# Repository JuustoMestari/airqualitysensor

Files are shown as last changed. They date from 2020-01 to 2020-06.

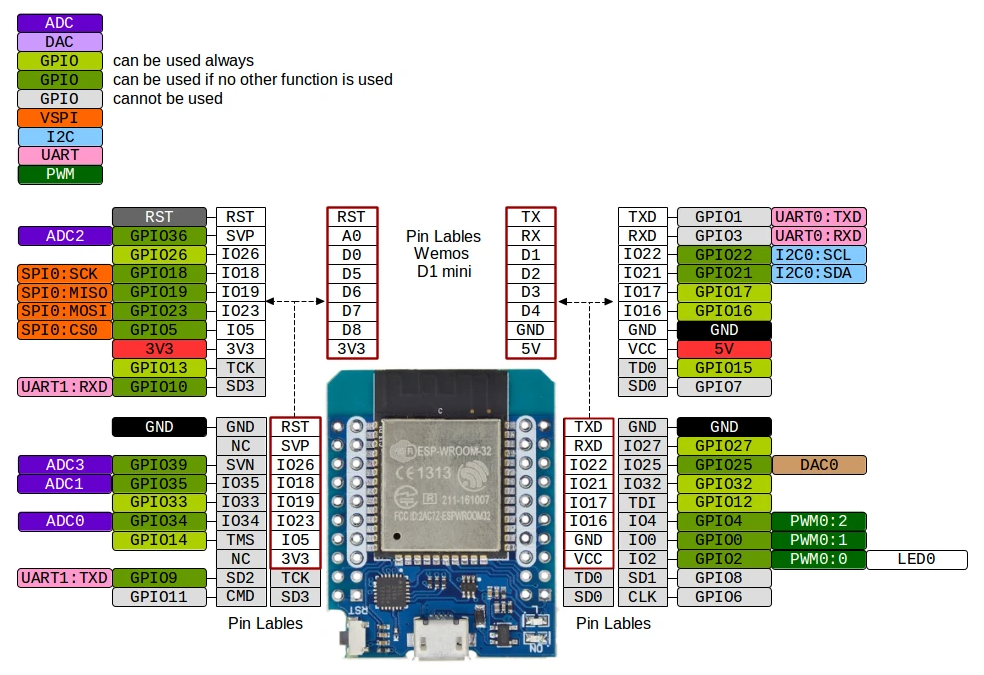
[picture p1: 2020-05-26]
docs/esp32_mini_pinout.png

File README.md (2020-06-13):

# Air quality sensor
## Device
- ESP32 board : https://ebay.to/39Jhv0x
## Air quality sensor
- PMS7003 : https://download.kamami.com/p564008-p564008-PMS7003%20series%20data%20manua_English_V2.5.pdf
## Temperature/Humidity sensor
- DHT22 : https://www.sparkfun.com/datasheets/Sensors/Temperature/DHT22.pdf
## Pinout
| ESP32 | DHT22 | PMS7003 |
| --- |:---:| ---:|
|VIN		 | | |
|GND		 | | |
|RST | |RST |
|IO17		 | |RX |
|IO16		 | |TX |
|3V3	 |VCC |VCC |
|GND	 |GND |GND |	
|IO4 |DATA | |	

## Libraries
- Micro Web Server : https://github.com/jczic/MicroWebSrv
- pms7003+AQI : https://github.com/pkucmus/micropython-pms7003

## firmware
- Download latest version of micropython for ESP32 : http://micropython.org/download#esp32
- Flash using instructions from micropython firmware download website using esptool : https://github.com/espressif/esptool . Esptool requires python module "pyserial" (pip install pyserial)
```console
python esptool.py --chip esp32 --port COM3 erase_flash
```
```console
python esptool.py --chip esp32 --port COM3 --baud 460800 write_flash -z 0x1000 esp32-20190125-v1.xxxxx.bin
```

## rshell
Install with 
```console
sudo pip3 install rshell
```
```console
pip install rshell
```
List files on device
```console
rshell -p COM3 ls /pyboard
```
Clear files on device
```console
rshell -p COM3 rm -r /pyboard/
```
Copy all files to device (doesn't seem to work on windows)
```console
rshell -p COM3 cp -r device/* /pyboard
```
Copy single file at a time (windows)
```console
rshell -p COM3 cp main.py /pyboard
```

## serial
You can monitor what is going on with the device by connecting with a client like Putty.  
Set port (COMX or /dev/ttyUSBX) and speed to 115200. Press reset button (EN) on ESP32.

# TODO
- ~~sync time with ntp server~~
- ~~add DHT22 logic~~
- improve logic if pms7003 returns AQI of 0
- improve UI
  - ~~add gauges~~
  - ~~add time series (1 min, 10min, 30min, 1 hour)~~
  - ~~add current time~~
  - ~~add flash space~~
  - ~~use progressbar for flash space~~
  - automatically refresh UI every minute
  - ~~improve page's css so graph is responsive, using flex~~
  - Fix metric colors
  - ~~change graph scale depending on period (1,10,30,60)~~
  - ~~improve display on mobile~~

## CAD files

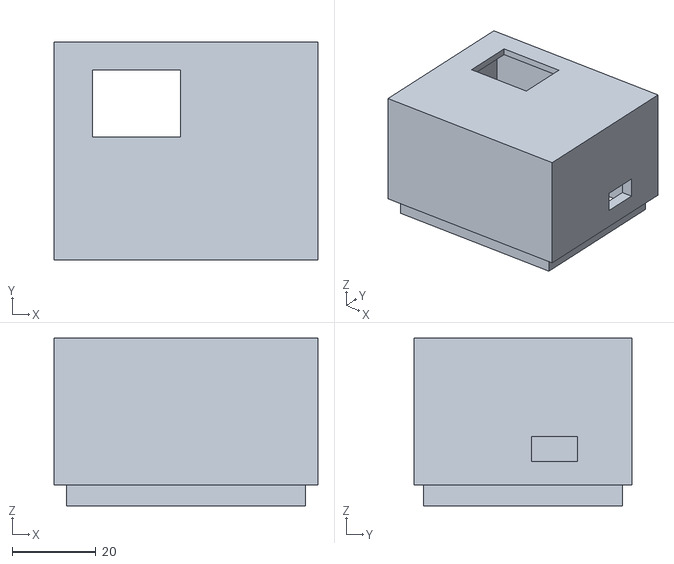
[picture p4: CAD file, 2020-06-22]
case/case_cover.stl
63.0 x 52.0 x 40.0

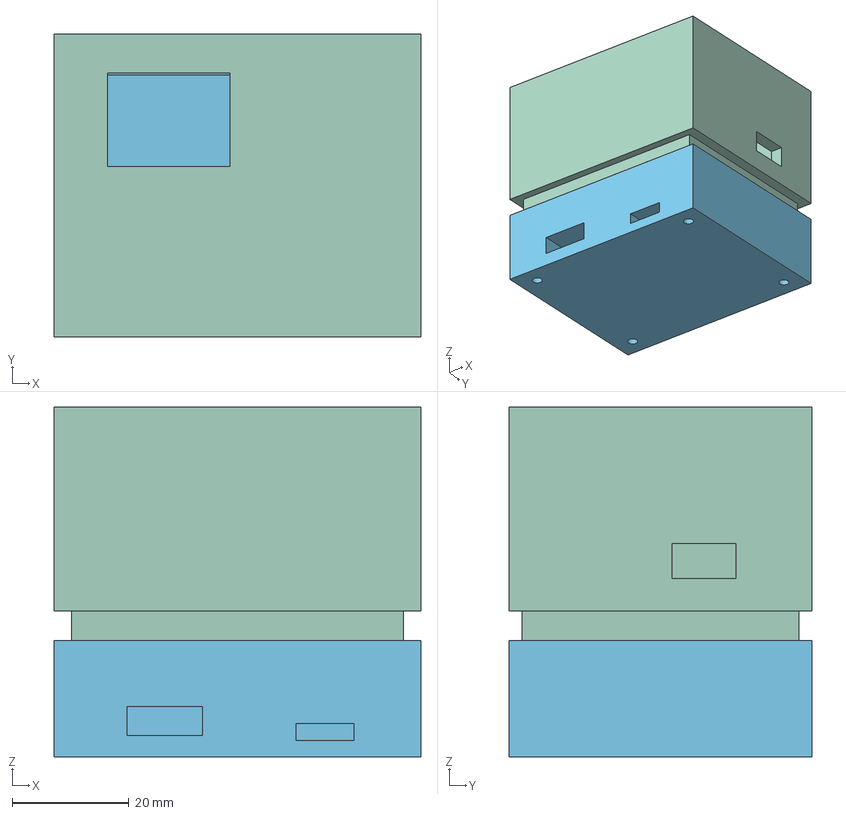
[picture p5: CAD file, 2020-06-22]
case/case.FCStd
63.0 x 52.0 x 60.0 mm
cover

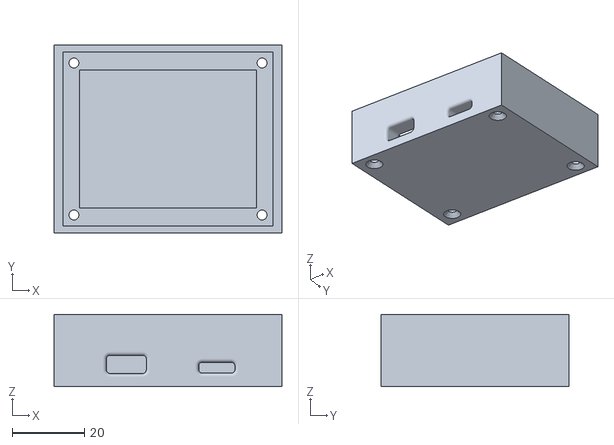
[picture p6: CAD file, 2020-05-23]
case/case_1.stl
63.0 x 52.0 x 20.0

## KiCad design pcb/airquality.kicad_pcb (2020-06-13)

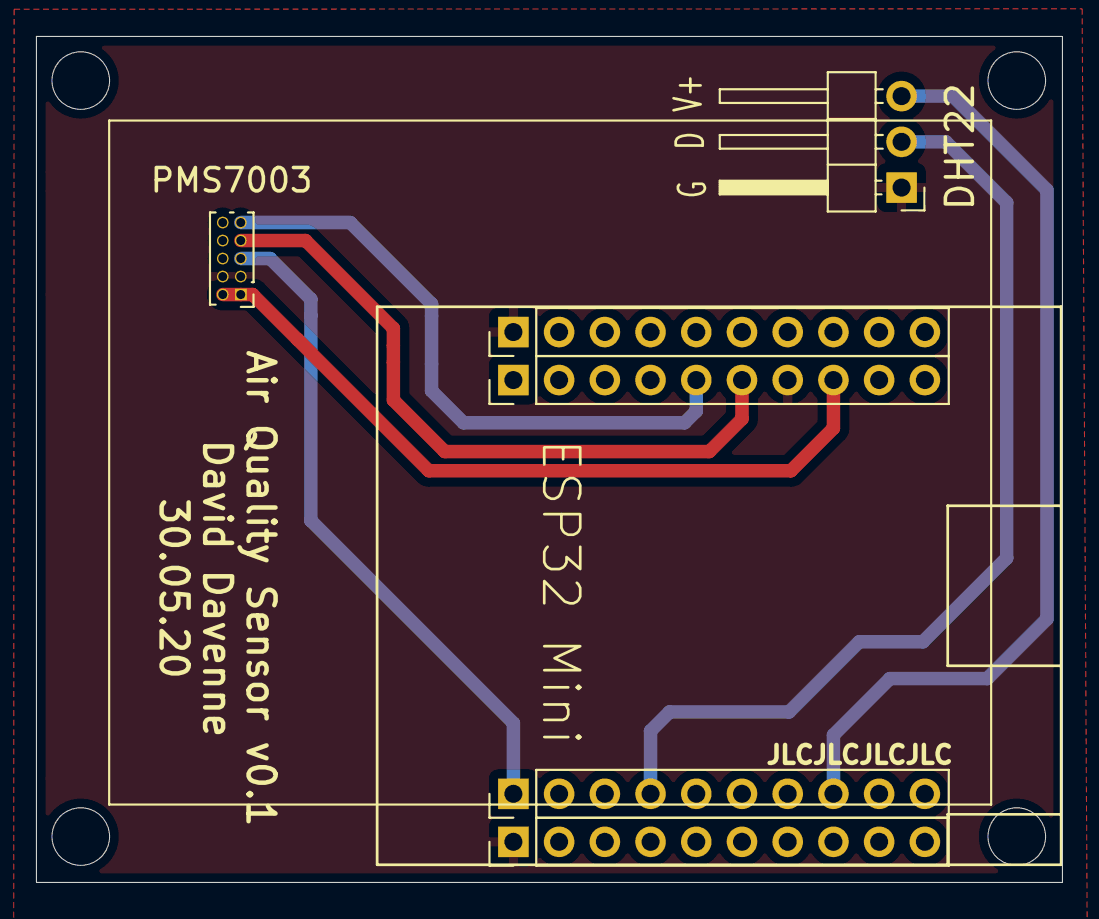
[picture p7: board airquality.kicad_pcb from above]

Board: 2 copper layers, 57.0 x 47.0 mm, 3 parts (0 on the bottom side), 7 nets.

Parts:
DHT22: DHT22; PinHeader_1x03_P2.54mm_Horizontal
ESP32 Mini: ESP32_Wemos
PMS7003: PMS7003; PinHeader_2x05_P1.00mm_Vertical

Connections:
5V: ESP32 Mini.13, PMS7003.1, PMS7003.2
/3V3: DHT22.3, ESP32 Mini.28
/IO18: DHT22.2, ESP32 Mini.24
/RST: ESP32 Mini.21, PMS7003.5
/RX: ESP32 Mini.15, PMS7003.7
/TX: ESP32 Mini.16, PMS7003.9
GND: DHT22.1, ESP32 Mini.1, ESP32 Mini.14, ESP32 Mini.40, PMS7003.3, PMS7003.4

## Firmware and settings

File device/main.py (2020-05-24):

from machine import Pin, Timer,RTC
import network
import ntptime 
import time
import ujson

import urequests as requests

#libraries
import webserver
import aggregate

#sensors
import sensors

#Info LED
INFO_LED = Pin(2, Pin.OUT)
ENDPOINT = '[http://your.endpoint.com/sensors]'
#Access Point data
SSID = 'SSID'
PASSWORD = 'PASSWORD'

#aggregate
aggcounter=1

def do_connect():
    """do_connect connects to the specified Access Point and Password"""
    sta_if = network.WLAN(network.STA_IF)
    if not sta_if.isconnected():
        print('connecting to network...')
        sta_if.active(True)
        sta_if.connect(SSID, PASSWORD)
        while not sta_if.isconnected():
            pass
    print('network config:', sta_if.ifconfig())
    INFO_LED.on()

def push_endpoint(timer):
    try:
        sensordata=sensors.get_sensors()
        #no need to do anything if air quality index is 0
        #if sensordata["metrics"]["aqi"]==0:
            #return
        #resp = requests.post(ENDPOINT, headers = {'content-type': 'application/json'},data=ujson.dumps(sensors.get_sensors()))
        #if resp.status_code != 200:
        #    print('Error : Status Code : {}. Message : {}'.format(resp.status_code,resp.text))

        #aggregate data
        global aggcounter
        if aggcounter%60==0:
            aggregate.run(60,sensordata)
            aggcounter=0
        if aggcounter%30==0:
            aggregate.run(30,sensordata)
        if aggcounter%10==0:
            aggregate.run(10,sensordata)
        aggregate.run(1,sensordata)
        aggcounter=aggcounter+1
        print(ujson.dumps(sensordata))  
    except Exception as e:
        print('Error: {}'.format(e))

#connect to wifi
do_connect()

#sync ntp
rtc = RTC()
ntptime.host = '192.168.39.1'
ntptime.settime()

#Clock timer
TIMR = Timer(-1)
TIMR.init(period=60000, mode=Timer.PERIODIC, callback=push_endpoint)

print(ujson.dumps(sensors.get_stats()))

#Start WebServer
webserver.start_webserver()

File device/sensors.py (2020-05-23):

"""sensors.py"""
import machine
import time
import utime
from machine import Pin, I2C
import ubinascii
import uos
import network
import dht

#libraries
from pms7003 import Pms7003
from aqi import AQI

pms = Pms7003(uart=2)
d = dht.DHT22(machine.Pin(18))

def get_sensors():
    sensors= {}
    pms_data=pms.read()
    d.measure()
    #add 946684800 because micropython epoch starts 2000-01-01 00:00:00 UTC
    sensors["timestamp"]=utime.time()+946684800
    sensors["metrics"]=pms_data
    #remove unecessary data from pms
    del sensors["metrics"]["CHECKSUM"]
    del sensors["metrics"]["ERROR"]
    #del sensors["metrics"]["FRAME_LENGTH"]
    del sensors["metrics"]["VERSION"]
    sensors["metrics"]["aqi"]=AQI.aqi(pms_data['PM2_5_ATM'], pms_data['PM10_0_ATM'])
    #TODO : Update temp and hum to use DHT22 library
    sensors["metrics"]["temperature"]=d.temperature()
    sensors["metrics"]["humidity"]=d.humidity()
    return sensors

def get_stats():
    stats={}
    uniqueID=ubinascii.hexlify(machine.unique_id()).decode('utf-8')
    sta_if = network.WLAN(network.STA_IF)
    os_data = uos.uname()
    #os_data => (sysname='esp32', nodename='esp32', release='1.12.0', version='v1.12-464-gcae77daf0 on 2020-05-21', machine='ESP32 module with ESP32')
    fs_stat = uos.statvfs('/')
    fs_size = fs_stat[0] * fs_stat[2]
    fs_free = fs_stat[0] * fs_stat[3]
    stats["device"]=uniqueID
    stats["version"]=os_data[2]
    stats["totalspace"]=fs_size
    stats["freespace"]=fs_free
    stats["time"]=utime.time()+946684800
    stats["essid"]=sta_if.config('essid')
    stats["mac"]=ubinascii.hexlify(sta_if.config('mac'),':').decode()
    stats["signalstrength"]=sta_if.status('rssi')
    stats["network"]=sta_if.ifconfig()
    return stats

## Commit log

2020-01-08 added extended sensors to README
2020-02-14 add mhz19b sensor
2020-05-21 update to use pms7003 device
2020-05-22 bug fix, take first element of array instead of full array
    [aggregate.py]
2020-05-23 add gitignore for kicad files
2020-05-23 add freecad model and stl
    [case.FCStd, case_1.stl]
2020-05-23 add kicad files
    [airquality.kicad_pcb, airquality.sch]
2020-05-23 fix aggregate to use average
    [aggregate.py]
2020-05-23 update pcb
    [airquality.kicad_pcb]
2020-05-24 switch from 100 to 50 records
2020-05-26 add esp32 mini pinout
2020-06-22 add case cover
    [case.FCStd, case_cover.stl]
